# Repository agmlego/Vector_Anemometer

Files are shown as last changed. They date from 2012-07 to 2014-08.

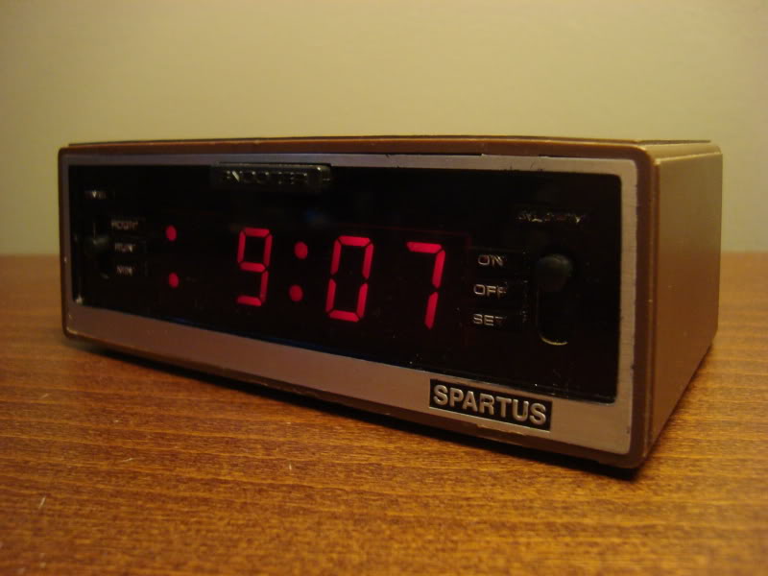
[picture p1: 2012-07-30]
Doc/LTC-637AX-12/Spartus.jpg

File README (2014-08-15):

This project is a modernization of W. Stephen Woodward's vector anemometer, 
detailed in the September 1997 issue of EDN (pp. 114-115, scanned copy found in 
the Doc directory of this repo). This modernization is specifically aimed at 
the small-boat sailing community, but should be able to be easily adapted for 
any wind monitoring project with little effort.

The system will consist of a faithful reproduction of W. Stephen Woodward's 
analog vector anemometer as a masthead wind sensor, with the addition of a 
small microcontroller to read the frequency-based data produced by the circuit. 
The data will be displayed by a series of PWM-dimmable 7-segment displays 
powered by a more powerful microcontroller, placed somewhere in the boat's 
cockpit and connected to the masthead sensor via UART, SPI, or I2C (TBD).

An eventual goal of this project is to allow NMEA 183 passthrough, taking a GPS 
on RS232, displaying select information on the cockpit displays, and injecting 
wind data into the NMEA sentences. An RS232 port will then feed the resulting 
NMEA sentences to a PC host for logging with the aim at automatic creation of 
vehicle polar plots. Alternatively, if budget allows, the system could log such 
data to SD card.

With reference to this repo, the Doc directory contains all relevant 
documentation for the project, including the project BOM, source material, 
notes, and diagrams. Eventually, installation notes and code reference manuals 
will be posted there as well.

The CAD directory will contain any physical CAD drawings, for suggested cases 
and mounting brackets.

The ECAD directory contains all electrical CAD drawings, created using EAGLE 
6.0 or better.

The Code directory contains all relevant code for the system, including a 
formatted version of W. Stephen Woodward's original GW-BASIC code.

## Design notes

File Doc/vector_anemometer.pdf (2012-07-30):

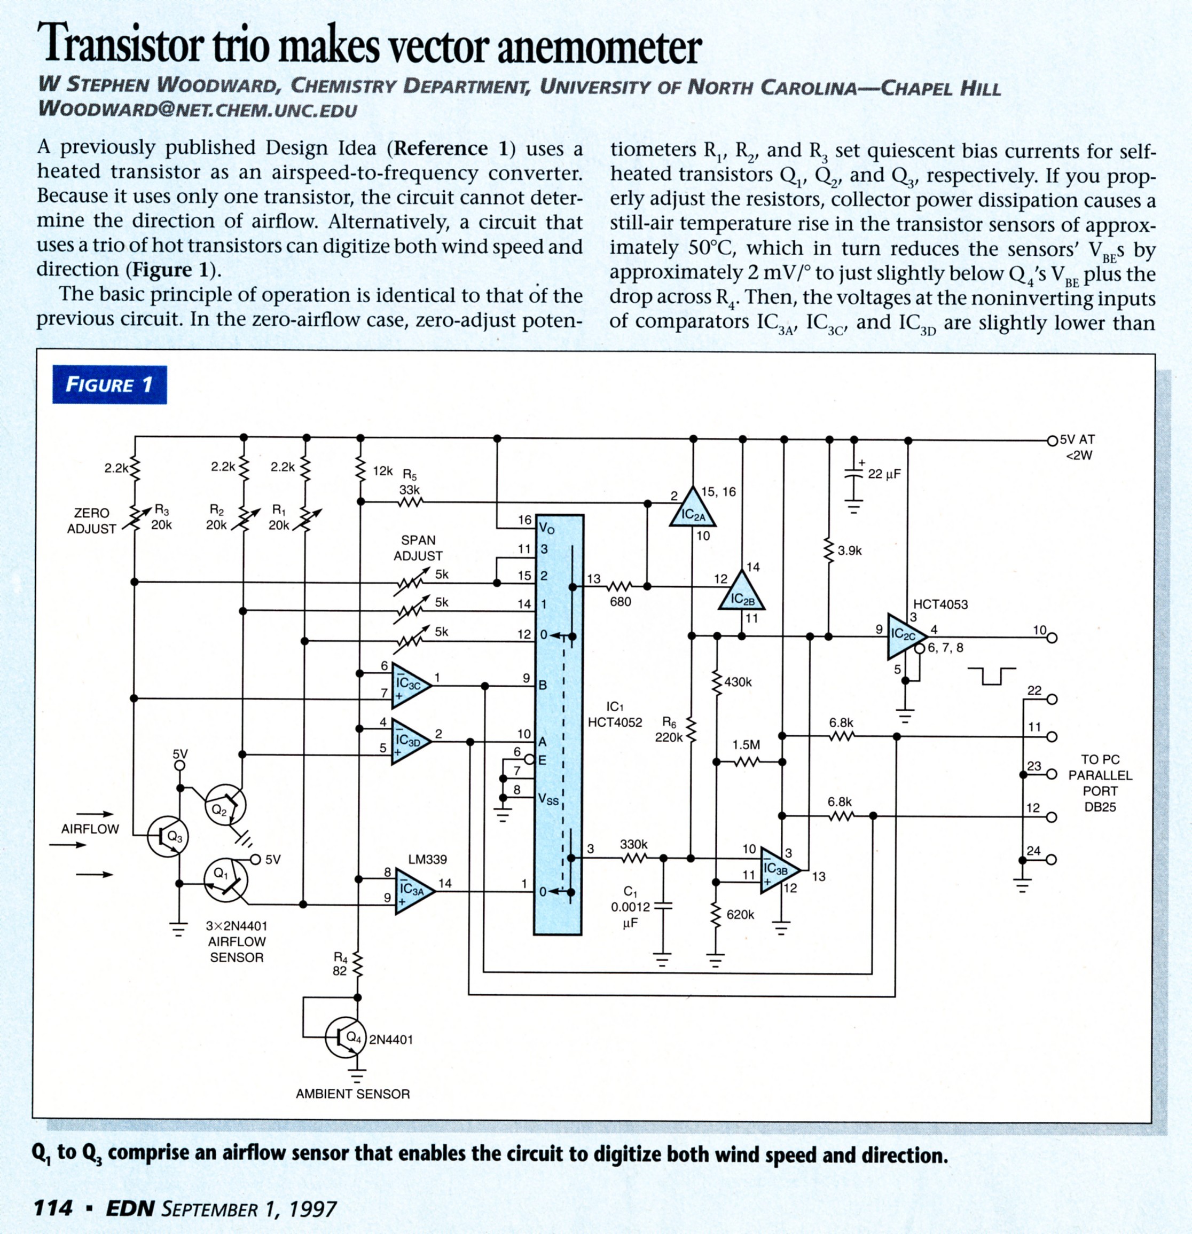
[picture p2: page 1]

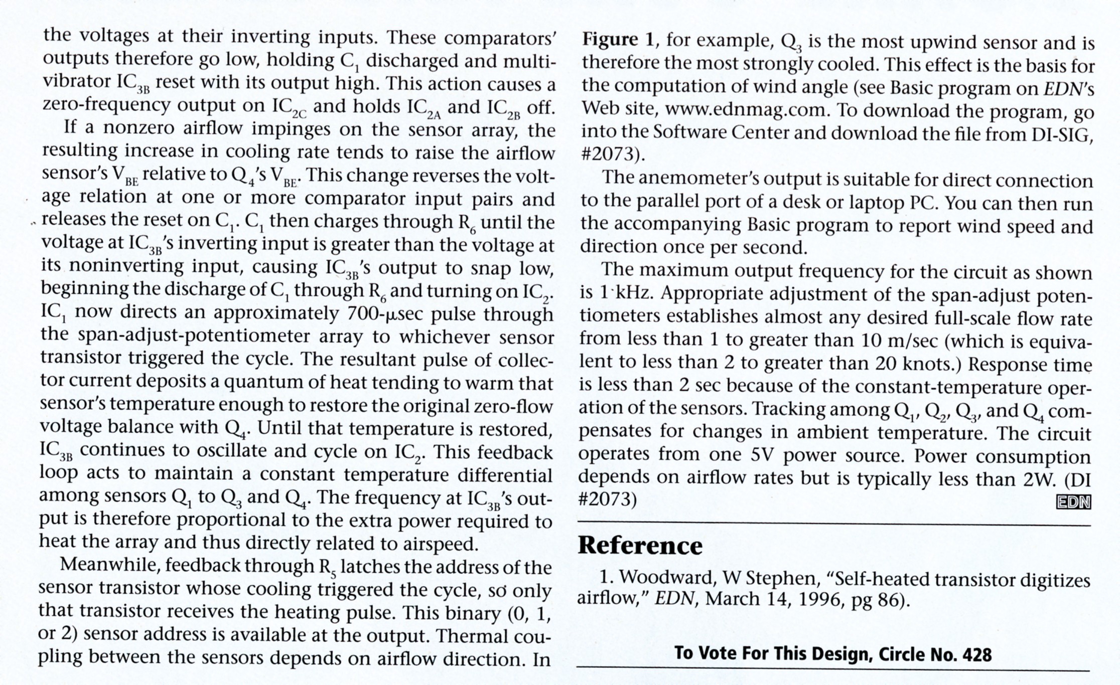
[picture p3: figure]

' Thermal Vector Transistor Anemometer Demo ... W. S. Woodward, 1996
anacal = 1: ' airspeed scale factor
tick% = 18.2065: '... # of MSDOS-compatible Time-of-Day "ticktocks"/second DEF SEG = 0: ' T.O.D. clock lives at memory addresses (&H46C,D)

' Pick a parallel port base address from the three a-priori' possibilities pp% = &H379: ' LPT1
IF INP(pp% + 1) = 255 THEN pp% = &H3BD: ' LPT2
IF INP(pp% + 1) = 255 THEN pp% = &H279: ' Last (and least)...LPT3
IF INP(pp% + 1) = 255 THEN PRINT "***ERROR...Parallel Port NOT Found***"; CHR$(7): STOP

windvane:
q0% = 0: q1% = 0: q2% = 0: ' Initialize sensor heatpulse sums
tclk% = PEEK(&H46C): ' Sample Time-of-Day cell
FOR i% = 1 TO tick%: ' Setup to sum heat pulses for ~1 second
WHILE PEEK(&H46C) = tclk%
q% = INP(pp%) AND &H70: ' Check for a heater pulse
IF q% < &H40 THEN IF q% = &H10 THEN q1% = q1% + 1 ELSE IF q% THEN q2% = q2% + 1 ELSE q0% = q0% + 1 WHILE (q% OR INP(pp%)) < &H40: WEND
WEND: tclk% = PEEK(&H46C)
NEXT: ' Tally clock ticktocks 'til 18 are accounted for
sum% = q0% + q1% + q2%: PRINT USING "####.# "; anacal * sum% * sum%;
IF sum% = 0 THEN PRINT : GOTO windvane
IF q0% < q1% THEN IF q0% < q2% THEN a% = q1%: b% = q2%: c% = q0%: g = 120 ELSE a% = q0%: b% = q1%: c% = q2%: g = 0 ELSE IF q1% < q2% THEN a% = q2%: b% = q0%: c% = q1%: g = 240 ELSE a% = q0%: b% = q1%: c% = q2%: g = 0
d% = a% + b% - c% - c%: IF d% > 0 THEN PRINT USING "###"; g + ABS(120 * ((b% - c%) / d%)) ELSE PRINT
GOTO windvane

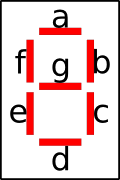
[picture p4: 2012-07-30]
Doc/LTC-637AX-12/LED_Segments.png

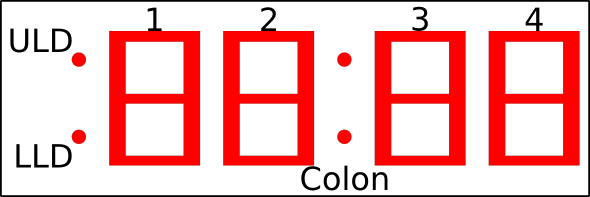
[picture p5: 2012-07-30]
Doc/LTC-637AX-12/LED_Display.png

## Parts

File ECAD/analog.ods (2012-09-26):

Qty | Value | Device | Parts | Part Number | Vendor | Price | Subtotal | $30.70
1 | 1X04 | 1X04 | SBW | ED90474-ND | Digikey | $1.558 | $1.56
4 | 2N3904 | 2N3904 | T1,T2,T3,T4 | 2N3904FS-ND | Digikey | $0.150 | $0.60
1 | 4052D | 4052D | IC4 | 568-3962-5-ND | Digikey | $0.423 | $0.42
1 | 74HCT4053D | 74HCT4053D | IC2 | 568-3963-5-ND | Digikey | $0.377 | $0.38
1 | 0.0012u | C-USC0805 | C1 | 720-1342-1-ND | Digikey | $1.085 | $1.09
1 | 22u | C-USC0805 | C2 | 587-1958-1-ND | Digikey | $0.503 | $0.50
1 | 10u | C-USC0805 | C3 | 311-1460-1-ND | Digikey | $0.130 | $0.13
1 | 0.1u | C-USC0805 | C4 | 587-1133-1-ND | Digikey | $0.374 | $0.37
1 | LM339D | LM339D | IC3 | 296-1013-5-ND | Digikey | $0.276 | $0.28
1 | MSP430G2231 | MSP430G2231 | IC1 | 296-25833-5-ND | Digikey | $1.535 | $1.54
2 | 6.8k | R-US_M0805 | R17,R18 | RHM6.8KKCT-ND | Digikey | $0.092 | $0.18
1 | 82 | R-US_M0805 | R4 | RHM82KCT-ND | Digikey | $0.115 | $0.12
3 | 2.2k | R-US_M0805 | R7,R8,R9 | RHM2.2KKCT-ND | Digikey | $0.115 | $0.35
1 | 12k | R-US_R0805 | R10 | RHM12KKCT-ND | Digikey | $0.115 | $0.12
1 | 680 | R-US_R0805 | R11 | RHM680KCT-ND | Digikey | $0.115 | $0.12
1 | 330k | R-US_R0805 | R12 | RHM330KAECT-ND | Digikey | $0.165 | $0.17
1 | 3.9k | R-US_R0805 | R13 | RHM3.9KKCT-ND | Digikey | $0.115 | $0.12
1 | 430k | R-US_R0805 | R14 | P430KADCT-ND | Digikey | $0.230 | $0.23
1 | 620k | R-US_R0805 | R15 | P620KADCT-ND | Digikey | $0.230 | $0.23
1 | 1.5M | R-US_R0805 | R16 | RHM1.5MKCT-ND | Digikey | $0.115 | $0.12
1 | 47k | R-US_R0805 | R19 | RHM47KKCT-ND | Digikey | $0.115 | $0.12
1 | 33k | R-US_R0805 | R5 | RHM33KKCT-ND | Digikey | $0.115 | $0.12
1 | 220k | R-US_R0805 | R6 | RHM220KAECT-ND | Digikey | $0.165 | $0.17
1 | TPS77333 | TPS77333 | IC5 | 296-8113-5-ND | Digikey | $2.380 | $2.38
3 | 20k | TRIM_US-SM-42/43W | R1,R2,R3 | SM-42TW203CT-ND | Digikey | $2.593 | $7.78
3 | 5k | TRIM_US-SM-42/43W | R40,R50,R60 | SM-42TW502CT-ND | Digikey | $2.593 | $7.78
1 | GLX-S-88M | GLX-S-88M | X1 | 806-GLX-S-88M-50 | Mouser | $3.780 | $3.78

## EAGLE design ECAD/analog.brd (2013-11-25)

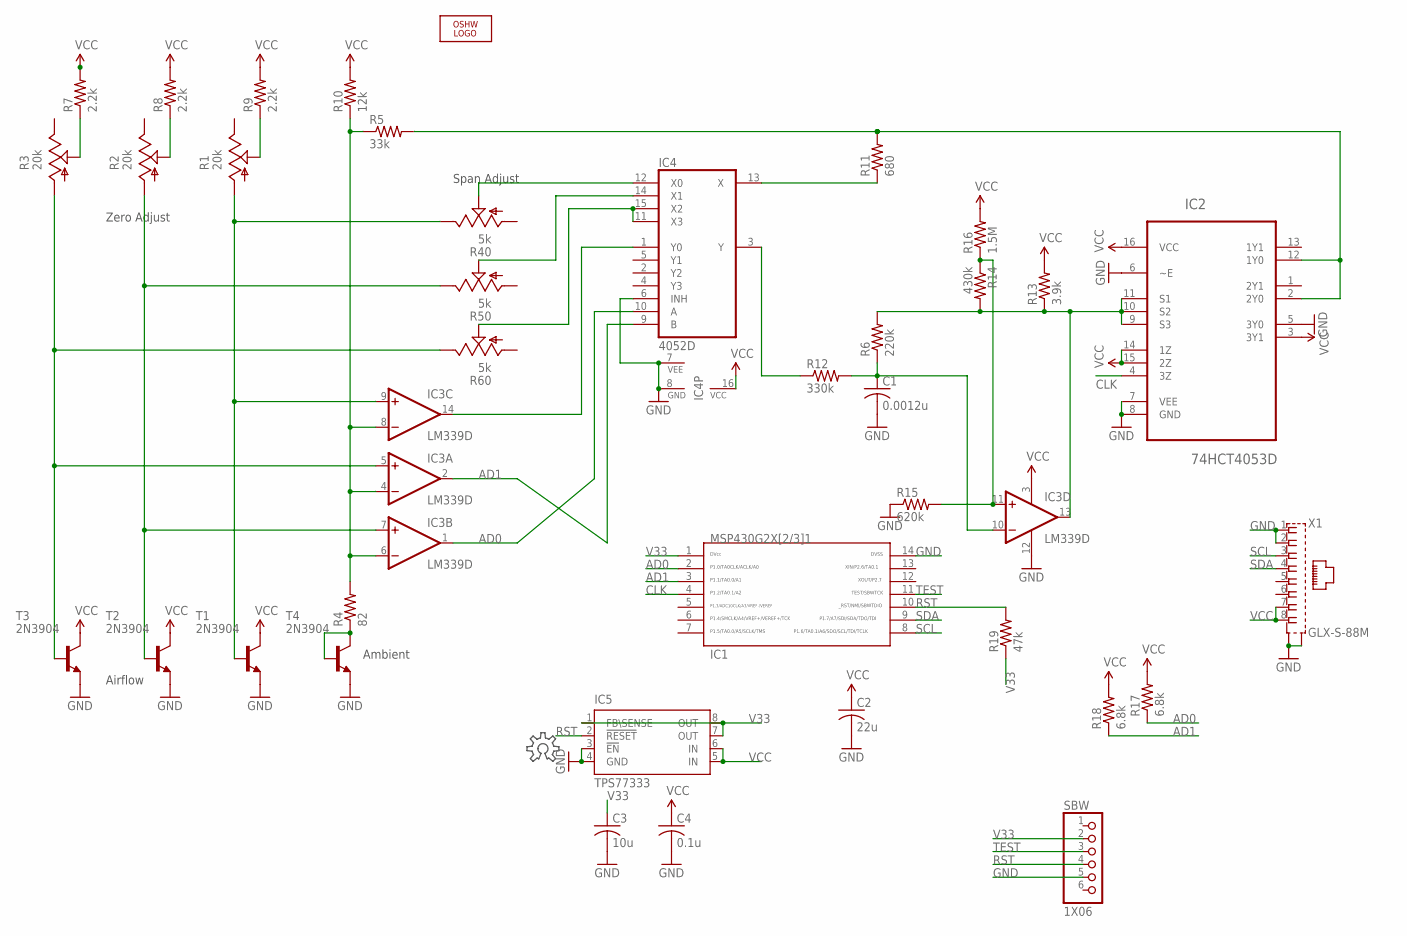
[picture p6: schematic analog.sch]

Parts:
C1: 0.0012u; C0805
C2: 22u; C0805
C3: 10u; C0805
C4: 0.1u; C0805
IC1: G2X[2/3]1---PW14; PW14
IC2: 74HCT4053D; SOIC127P600X175-16N
IC3: LM339D; SO14
IC4: 4052D; SO16
IC5: TPS77333
LOGO1: OSHW_LOGO_FILLX0150-NT; OSHW_FILLX150_NOTEXT
R1, R2, R3: 20k; SM-42/43W
R4: 82; M0805
R5: 33k; R0805
R6: 220k; R0805
R7: 2.2k; M0805
R8, R9: 2.2k; R0805
R10: 12k; R0805
R11: 680; R0805
R12: 330k; R0805
R13: 3.9k; R0805
R14: 430k; R0805
R15: 620k; R0805
R16: 1.5M; R0805
R17, R18: 6.8k; M0805
R19: 47k; R0805
R40, R50, R60: 5k; SM-42/43W
SBW: 1X06
T1, T2, T3, T4: 2N3904; TO92
X1: GLX-S-88M

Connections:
AD0: IC1.2, IC3.1 (OUT), IC4.10 (A), R17.1
AD1: IC1.3, IC3.2 (OUT), IC4.9 (B), R18.1
CLK: IC1.4, IC2.4 (3Z)
GND: C1.2, C2.2, C3.2, C4.2, IC1.14, IC2.5 (3Y0), IC2.6 (~E), IC2.7 (VEE), IC2.8 (GND), IC3.12 (GND), IC4.6 (INH), IC4.7 (VEE), IC4.8 (GND), IC5.3 (!EN), IC5.4 (GND), R15.1, SBW.5, T1.3 (E), T2.3 (E), T3.3 (E), T4.3 (E), X1.1, X1.2, X1.S1, X1.S2
unnamed: R4.1, T4.1 (C), T4.2 (B)
unnamed: IC3.9 (+IN), R1.1 (A), R40.3 (E), T1.2 (B)
unnamed: IC4.12 (X0), R40.2 (S)
unnamed: IC4.14 (X1), R50.2 (S)
unnamed: IC4.11 (X3), IC4.15 (X2), R60.2 (S)
unnamed: R3.2 (S), R7.1
unnamed: R2.2 (S), R8.1
unnamed: R1.2 (S), R9.1
unnamed: IC3.4 (-IN), IC3.6 (-IN), IC3.8 (-IN), R4.2, R5.1, R10.1
unnamed: IC3.5 (+IN), R3.1 (A), R60.3 (E), T3.2 (B)
unnamed: IC3.7 (+IN), R2.1 (A), R50.3 (E), T2.2 (B)
unnamed: IC3.14 (OUT), IC4.1 (Y0)
unnamed: IC2.2 (2Y0), IC2.12 (1Y0), R5.2, R11.2
unnamed: IC4.13 (X), R11.1
unnamed: IC4.3 (Y), R12.1
unnamed: C1.1, IC3.10 (-IN), R6.1, R12.2
unnamed: IC2.9 (S3), IC2.10 (S2), IC2.11 (S1), IC3.13 (OUT), R6.2, R13.1, R14.2
unnamed: IC3.11 (+IN), R14.1, R15.2, R16.1
RST: IC1.10, IC5.2 (!RESET), R19.2, SBW.4
SCL: IC1.8, X1.3
SDA: IC1.9, X1.4
TEST: IC1.11, SBW.3
V33: C3.1, IC1.1, IC5.1 (FB\SENSE), IC5.7 (OUT), IC5.8 (OUT), R19.1, SBW.2
VCC: C2.1, C4.1, IC2.3 (3Y1), IC2.14 (1Z), IC2.15 (2Z), IC2.16 (VCC), IC3.3 (V+), IC4.16 (VCC), IC5.5 (IN), IC5.6 (IN), R7.2, R8.2, R9.2, R10.2, R13.2, R16.2, R17.2, R18.2, T1.1 (C), T2.1 (C), T3.1 (C), X1.7, X1.8

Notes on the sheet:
Zero Adjust
Span Adjust
Ambient
Airflow

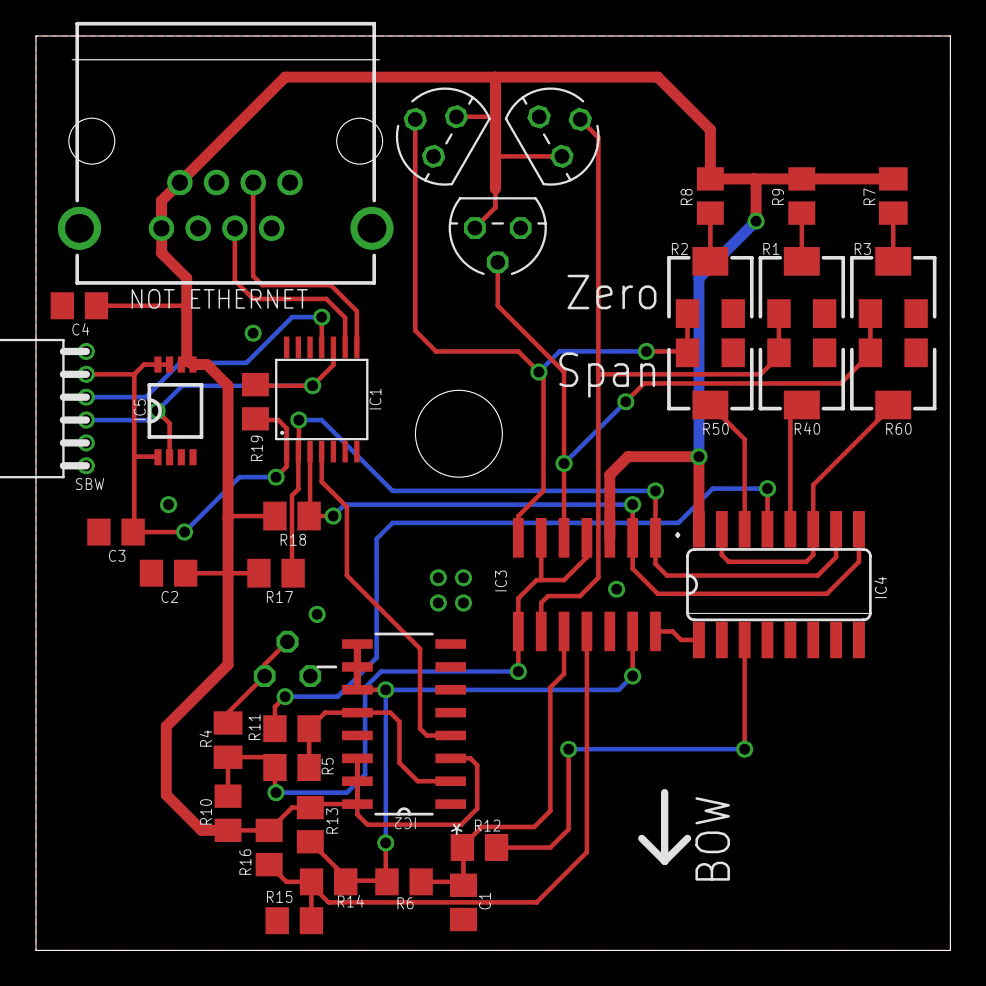
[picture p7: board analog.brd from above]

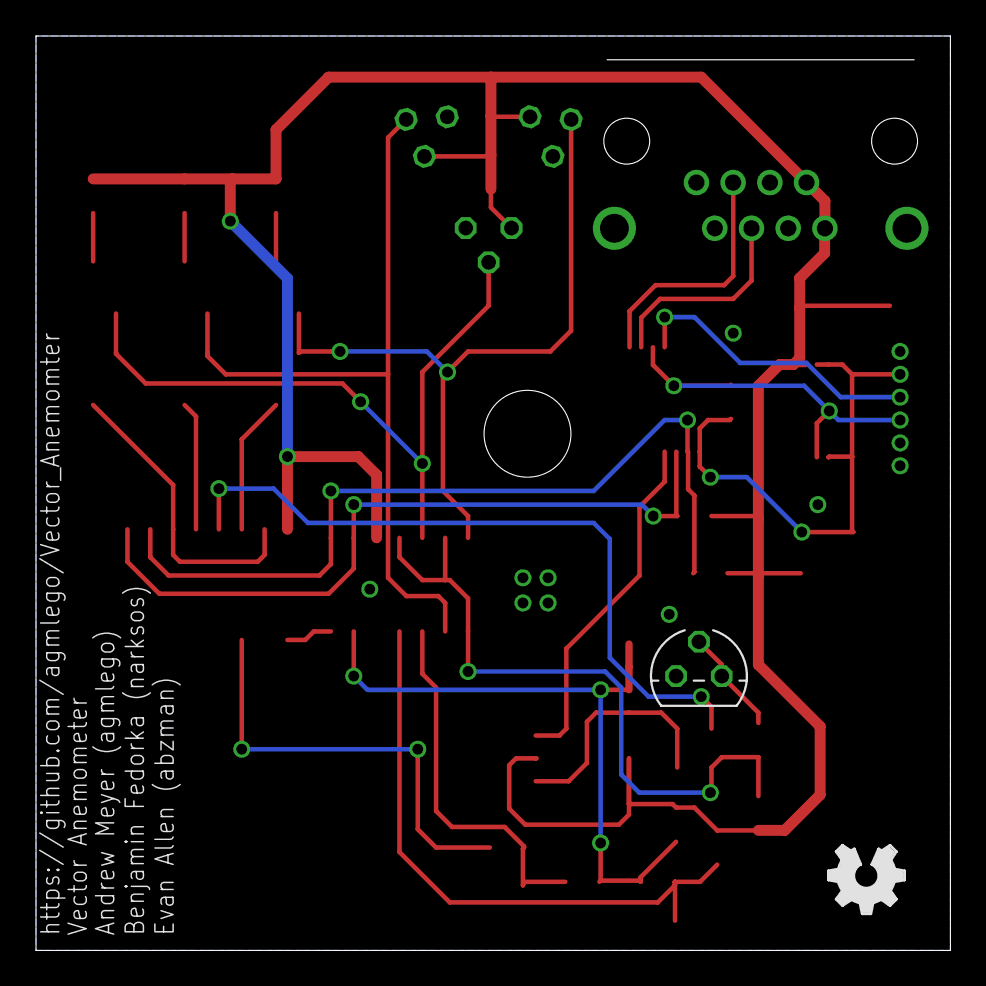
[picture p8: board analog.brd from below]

Board: 2 copper layers, 50.8 x 50.8 mm, 38 parts (3 on the bottom side), 28 nets.

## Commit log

2012-07-30 Initial commit of current project files.
    [analog.brd, analog.sch]
2012-07-30 Added documentation on an LED display (LTC-637AX-12) briefly considered for display in this project.
2012-08-25 Began work on PCB artwork, cleaned up schematic a little.
    [analog.brd, analog.sch]
2012-08-25 Formatted README and LICENSE to better flow
2012-08-30 Initial draft layout of analog board. Needs cleanup before routing.
    [analog.brd]
2012-09-17 Added MSP layout to custom.lbr Added MSP micro to schematic (not complete).
    [analog.brd, analog.sch]
2012-09-22 Added MSP430 Spy-By-Wire header, edited layout for production, added and cleaned up silk.
    [analog.brd, analog.sch]
2012-09-26 Added BOM for analog board in ODS format, edited schematic to comply with EAGLE 6.2 rules.
    [analog.ods, analog.sch]
2013-11-25 Replaced SOIC-8 package for TSSOP-8 on TPS77333. Rerouted traces to give more space around the 1/4-20 bolt hole.
    [analog.brd, analog.sch]

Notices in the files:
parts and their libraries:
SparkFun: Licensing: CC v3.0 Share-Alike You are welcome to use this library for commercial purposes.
